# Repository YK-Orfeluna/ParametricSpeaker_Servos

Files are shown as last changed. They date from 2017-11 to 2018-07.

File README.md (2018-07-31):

# ParametricSpeaker_Servos
## 注意点
全ての3Dプリンタを同時に利用できるわけではありません．<br>
どの3Dプリンタが稼働中で，どの3Dプリンタを使えるかはわからないので，全ての形式のデータを持っていくことを推奨します．<br>
データはUSBメモリやSDカードに保存して持って行って，備え付けのPCを通して，3Dプリンタ用に用意されたUSBメモリやSDカードに入れます．

## [stl_data](./stl_data)
教室には，この`.stl`形式のファイルを持っていけば，印刷できます．<br>
ただし，各3Dプリンタに合わせた形式のファイルに変換する必要があります．<br>
教室奥の小さな3Dプリンタを使う場合，`.stl`形式のデータから直接印刷できるようです．

### 注意点
上記の「小さな3Dプリンタ」は，**台座へのマテリアルの定着率が低い**，（ガードするものが何もないので）**対流の影響を受ける**といった問題点があり，トライアンドエラーが多数必要になる可能性があります．<br>

## [123dx_data](./123dx_data)
3ds Max用のデータです．<br>
拡張子は全て*.123dx*です．

## [print_data](./print_data)
Ultimaterの3Dプリンタで印刷できるように，データ形式を`.stl`から`.gcode`に変換したものです．<br>
変換時の設定は，印刷速度はFast，マテリアルの充填はSolid（フル充填）です．<br>
**印刷速度を速め**にしているので，出来上がりは荒くなります．<br>
マテリアルをフル充填させているので，印刷時間の増加とマテリアルの使用量の増加，出来上がり作品の重量増加という問題点は生じますが，**出来上がり作品の強度は向上**します．<br>
必要に応じて，印刷速度とマテリアル充填の割合を変更することが可能ですが，その場合は再度`.stl`から`.gcode`への変換を行う必要があります．<br>
つまり，印刷設定を変更する度に，`.stl`から`.gcode`への変換を行う必要があります．<br>
全て，接地面のsupportは有りにしています．

### [Ultimater_2_Extended+](./print_data/Ultimater_2_Extended+)
"Ultimater 2 Extended+"で印刷する時に使用します．<br>
印刷はSDカードを本体に差し込んで，そこからデータを読み込んで行います<br>
所要時間の目安は以下のとおりです．

|パーツ|所要時間|
|:---:|:-----:|
|[micstand](#micstand)|*1h 33m*|
|[param](#param)|*2h 17m*|
|[servo_x](#servo_x)|*1h 50m*|
|[servo_y](#servo_y)|*0h 53m*|

### [Ultimater_3_Extended](./print_data/Ultimater_3_Extended)
"Ultimater 3 Extended"で印刷する時に使用します．<br>
印刷はUSBメモリを本体に差し込んで，そこからデータを読み込んで行います<br>
所要時間の目安は以下のとおりです．

|パーツ|所要時間|
|:---:|:-----:|
|[micstand](#micstand)|*1h 45m*|
|[param](#param)|*2h 48m*|
|[servo_x](#servo_x)|*2h 07m*|
|[servo_y](#servo_y)|*1h 05m*|

## 各パーツの解説
### micstand

* servo_yをマイクスタンドに取り付けるためのパーツ
* **回しすぎると，マイクスタンドの雄ねじがこのパーツを貫通**してしまうので注意
* 2つにわかれているので，重ねて使う

### param

* パラメトリックスピーカの超音波照射面に装着するパーツ
* servo_yと合体させる

### servo_y

* y軸方向に回転するサーボモータに装着する
* paramとservo_xとそれぞれ合体させる

### servo_x

* x軸方向に回転するサーボモータに装着する
* micstandとservo_yとそれぞれ合体させる

## 組み立て方

<!-- ### 超音波発振子を1セット使う場合

#### 必要なもの
|名称|個数|
|:---:|:---:|
|出力した全パーツ|各1個ずつ|
|サーボモータ（x軸用）|1|
|サーボモータ（y軸用）|1|
|なべ小ネジ（M3×30mm）|4|
|なべ小ネジ（M3×15mm）|4|
|さら小ネジ（M4×15mm）|4|
|なべ小ネジ（M4×？mm）|4| -->

### 超音波発振子を2セット使う（増設）場合

#### 必要なもの
|名称|個数|
|:---:|:---:|
|出力した全パーツ|各1個ずつ|
|サーボモータ（x軸用）|1|
|サーボモータ（y軸用）|1|
|なべ小ネジ（M3×30mm）|8|
|なべ小ネジ（M3×15mm）|4|
|さら小ネジ（M4×15mm）|4|
|なべ小ネジ（M4×？mm）|4|

#### 組み立て手順

1. *param*に*servo_y*を取り付けるする
	* なべ小ネジ（M3×15mm）を4本使う
	* ネジが入りにくい時は，ドリルなどで穴を拡張する

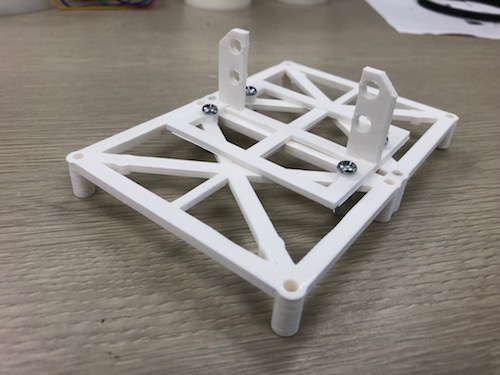
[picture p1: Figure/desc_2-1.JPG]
paramとservo_yの取り付け
	

2. *param*にパラメトリックスピーカの超音波発振子を取り付ける
	* なべ小ネジ（M3×30mm）を8本使う
	* 超音波発振子の向きが全て同じになるようにする
		* 向きが揃わないと，発振子同士が干渉し合って音が消失する

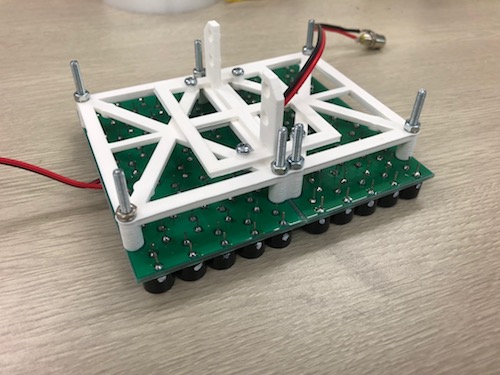
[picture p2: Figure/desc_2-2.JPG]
スピーカ取り付け
	
	
3. *servo_y*にサーボモータ（y軸用）を取り付ける
	* さら小ネジ（M4×15mm）を4本使う
	* 事前にサーボモータの向きをArduinoなどを使って90度に合わせておくと良い

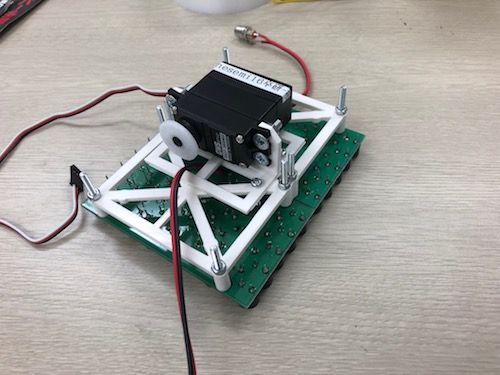
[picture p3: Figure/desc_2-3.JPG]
サーボモータY取りつけ
	

4. サーボモータ（y軸用）に*servo_x*を取り付ける
	
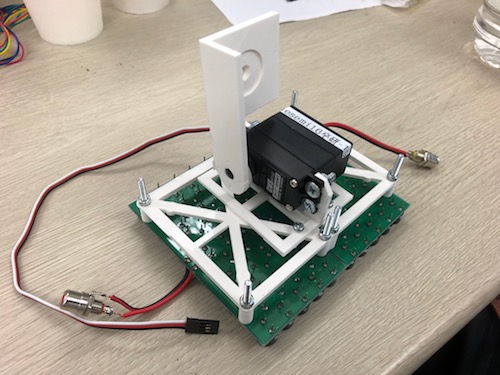
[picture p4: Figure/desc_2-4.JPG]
servo_x取り付け
	
	
5. サーボモータ（x軸用）に*micstand*を取り付ける
	* なべ小ネジ（M4×？mm）を4本使う

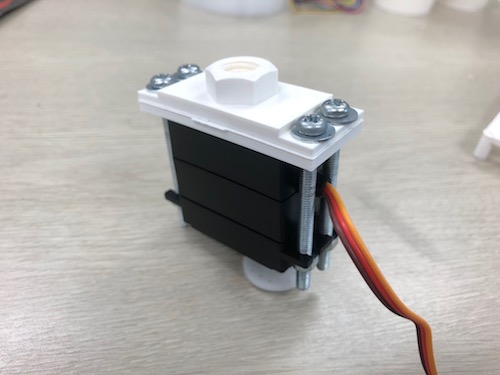
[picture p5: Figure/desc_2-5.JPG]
micstand取り付け
	
	
5. *servo_x*にサーボモータ（x軸用）を取り付ける
	
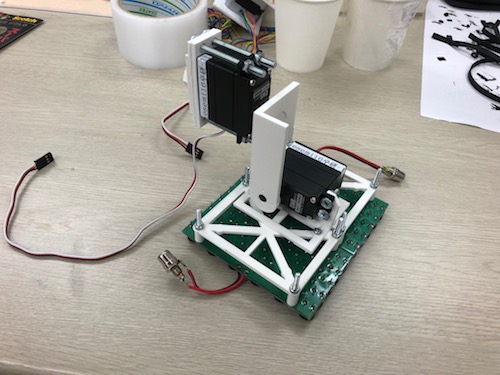
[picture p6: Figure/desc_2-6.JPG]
サーボモータX取り付け
	

6. マイクスタンドに取り付ける（完成）
	* 取り付けるときに回しすぎると，マイクスタンドの雄ねじ部分が*micstand*を**貫通**するので要注意
	
	<!-- ![マイクスタンド取り付け](./Figure/desc_2-7.JPG) -->

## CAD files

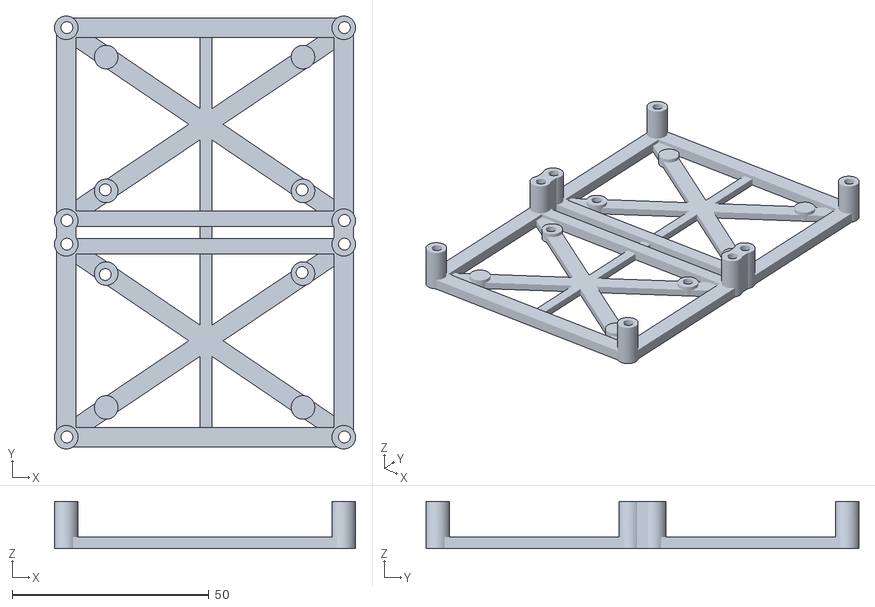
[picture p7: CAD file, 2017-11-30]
stl_data/param.stl
76.5 x 110.0 x 12.0

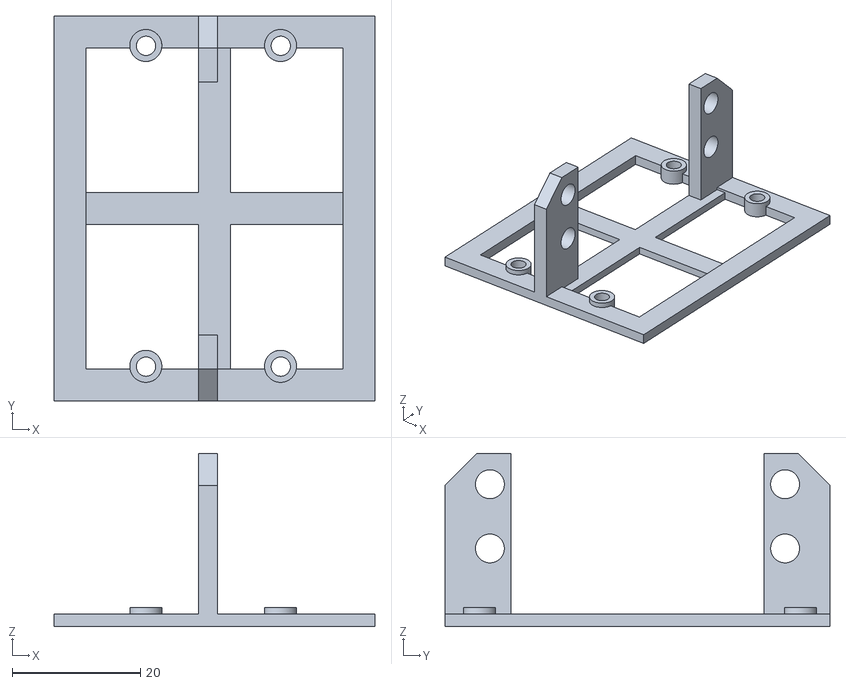
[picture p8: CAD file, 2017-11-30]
stl_data/serve_y.stl
50.0 x 60.0 x 27.0

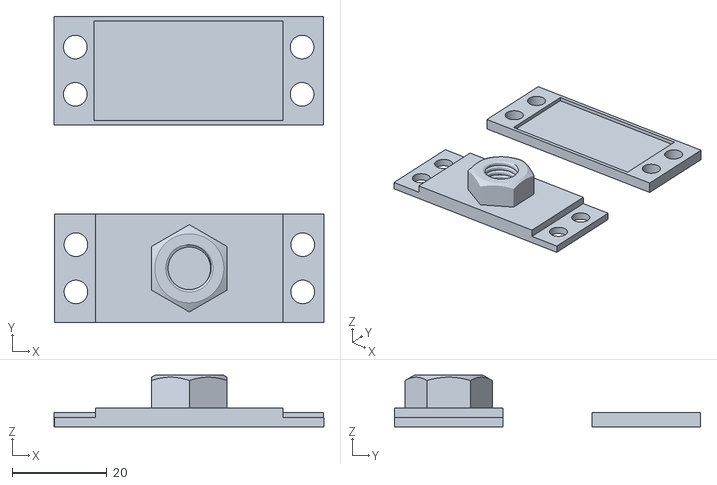
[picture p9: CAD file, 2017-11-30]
stl_data/micstand.stl
57.1 x 64.8 x 10.9

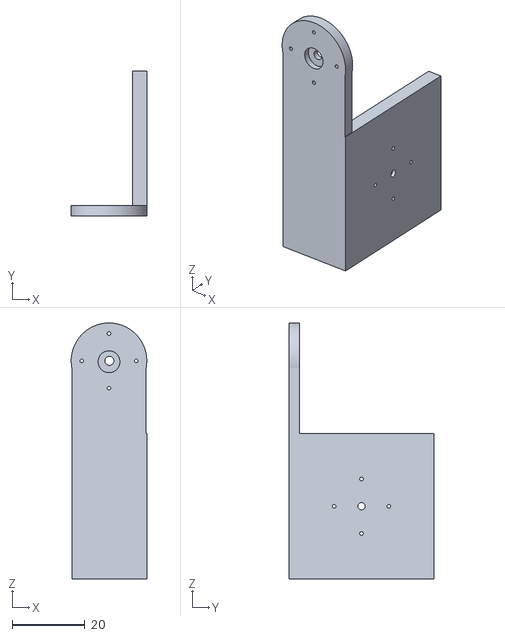
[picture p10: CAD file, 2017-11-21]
stl_data/servo_x.stl
20.8 x 40.0 x 70.4

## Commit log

2017-11-29 add infomation about STL
2017-11-30 Correction screw-holes
    [micstand.stl, param.stl, serve_y.stl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]
2018-02-15 update branch
    [micstand.stl, param.stl, serve_y.stl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]
2018-02-15 add new gcode data
    [micstand.stl, param.stl, serve_y.stl]
